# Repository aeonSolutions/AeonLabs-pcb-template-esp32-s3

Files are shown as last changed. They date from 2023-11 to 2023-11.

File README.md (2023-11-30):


  
 
 

<a href="https://trackgit.com">
trackgit-views
</a>




[](https://www.buymeacoffee.com/migueltomas)

[PCB-Prototyping-Catalogue](https://github.com/aeonSolutions/PCB-Prototyping-Catalogue)  >>  [DIY & Maker](https://github.com/aeonSolutions/PCB-Prototyping-Catalogue/blob/main/DIY-Maker/README.md)   >> 
 [DIY & Makers PCBs essentials: modules / Shields](https://github.com/aeonSolutions/PCB-Prototyping-Catalogue/blob/main/PCB-Shields/README.md)  >>  ESP32 S3 

<p align="right">
 <a href="https://github-com.translate.goog/aeonSolutions/PCB-Prototyping-Catalogue/tree/main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">Change Language</a> <br>
Last update: 30-11-2023
</p>

# PCB template ESP32 S3

<p align="center">
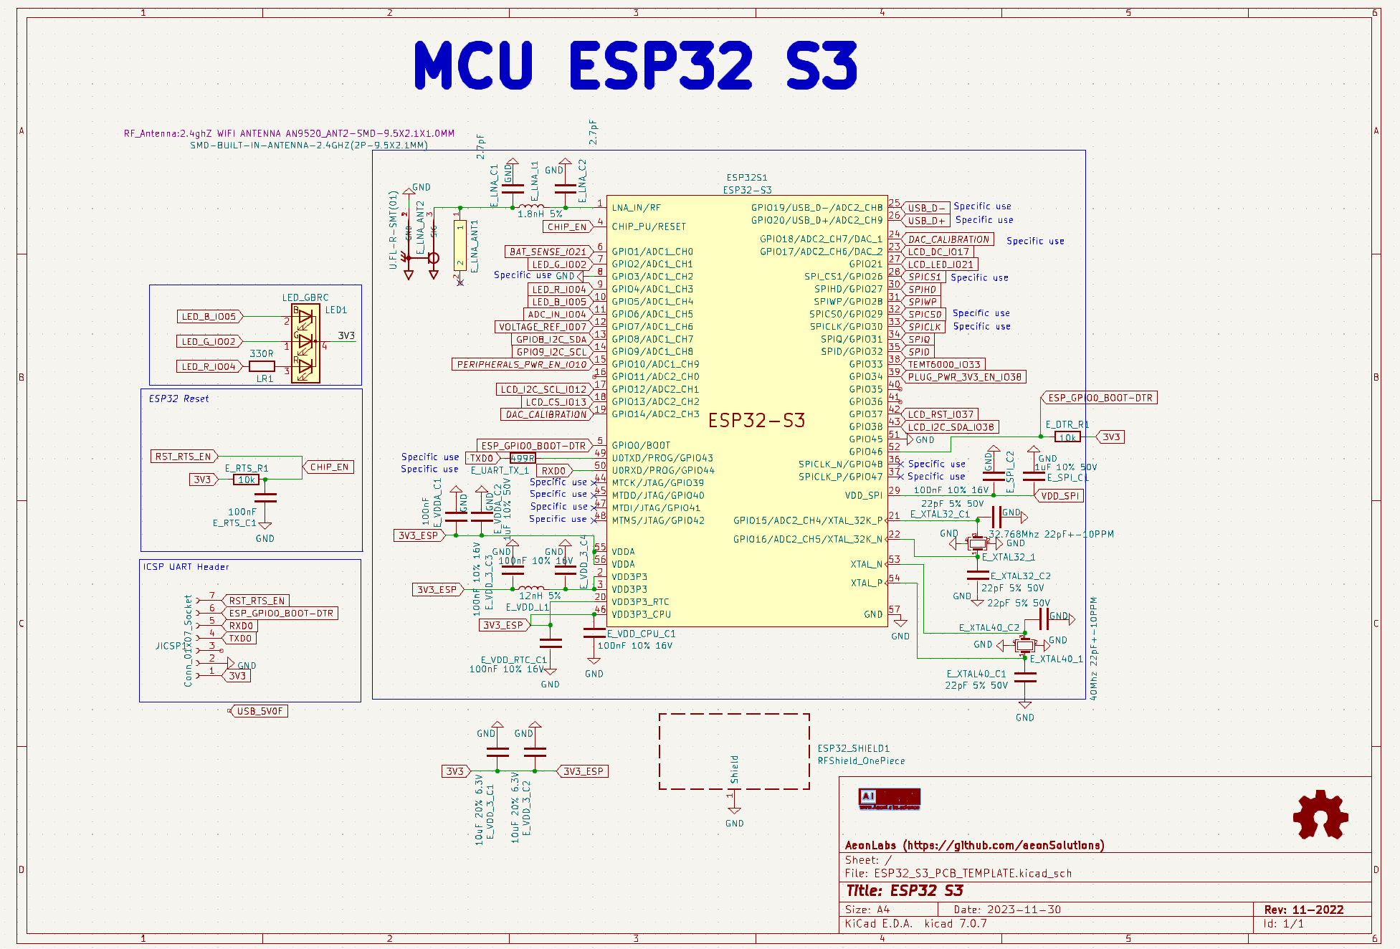
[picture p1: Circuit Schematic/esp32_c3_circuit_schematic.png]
   
</p>

#
## Firmware Download 
one can use the PCB in the repository [AeonLabs-MCU-Burner-USB-to-UART-TTL](https://github.com/aeonSolutions/AeonLabs-MCU-Burner-USB-to-UART-TTL) to program the ESP32 WROOM32 MCU on this PCB.

#

<br>

*Don't forget to LIKE , SHARE and subscribe the free whatsApp group* and if you liked this PCB consider buying me a cup of coffee. Links below.

## Liked it ? Get a Free PCB for yourself
Send me your Device or hardware and i will design a custom PCB for it. Free of charge. Contact-me on WhatsApp or email for more info. 

## Q&A WhatsApp Group
If you have any Questions or simply  like this kind of projects and want to stay updated with the latest research ideas and prototypes during the day and week, join the WhatsApp Group
[A.I. Things](https://chat.whatsapp.com/FkNC7u83kuy2QRA5sqjBVg)

## Fully assembled PCB
Alternatively, and if you do not want to build a PCB by yourself and like to buy one, you can do it here:

<p align="center">
   
</p>

<br />
<br />

## Author

You can get in touch with me on my LinkedIn Profile:

#### Miguel Tomas





You can also follow my GitHub Profile to stay updated about my latest projects: 

<br>

### Be supportive of my dedication and work towards technology education and buy me a cup of coffee
The PCB Desgin Files i provide here for anyone to use are free. If you like this Smart Device or use it, please consider buying me a cup of coffee, a slice of pizza or a book to help me study, eat and think new PCB design files.

<p align+"left">
<a href="https://www.buymeacoffee.com/migueltomas">
   
 </a>
<br>

</p>

<br />

### Make a donation on Paypal
Make a donation on paypal and get a TAX refund*.

(http://paypal.me/mtpsilva)

<br>

### Support all these open hardware projects and become a patreon  
Liked any of my PCB KiCad Designs? Help and Support my open work to all by becomming a LDAD Patreon.
In return I will give a free PCB design in KiCad to all patreon supporters. To learn more go to patreon.com. Link below.

(https://www.patreon.com/ldad)

#

### License

Before proceeding to download any of AeonLabs software solutions for open-source development and/or PCB hardware electronics development make sure you are choosing the right license for your project. See [AeonLabs Solutions for Open Hardware & Source Development](https://github.com/aeonSolutions/PCB-Prototyping-Catalogue/wiki/AeonLabs-Solutions-for-Open-Hardware-&-Source-Development) for more information.

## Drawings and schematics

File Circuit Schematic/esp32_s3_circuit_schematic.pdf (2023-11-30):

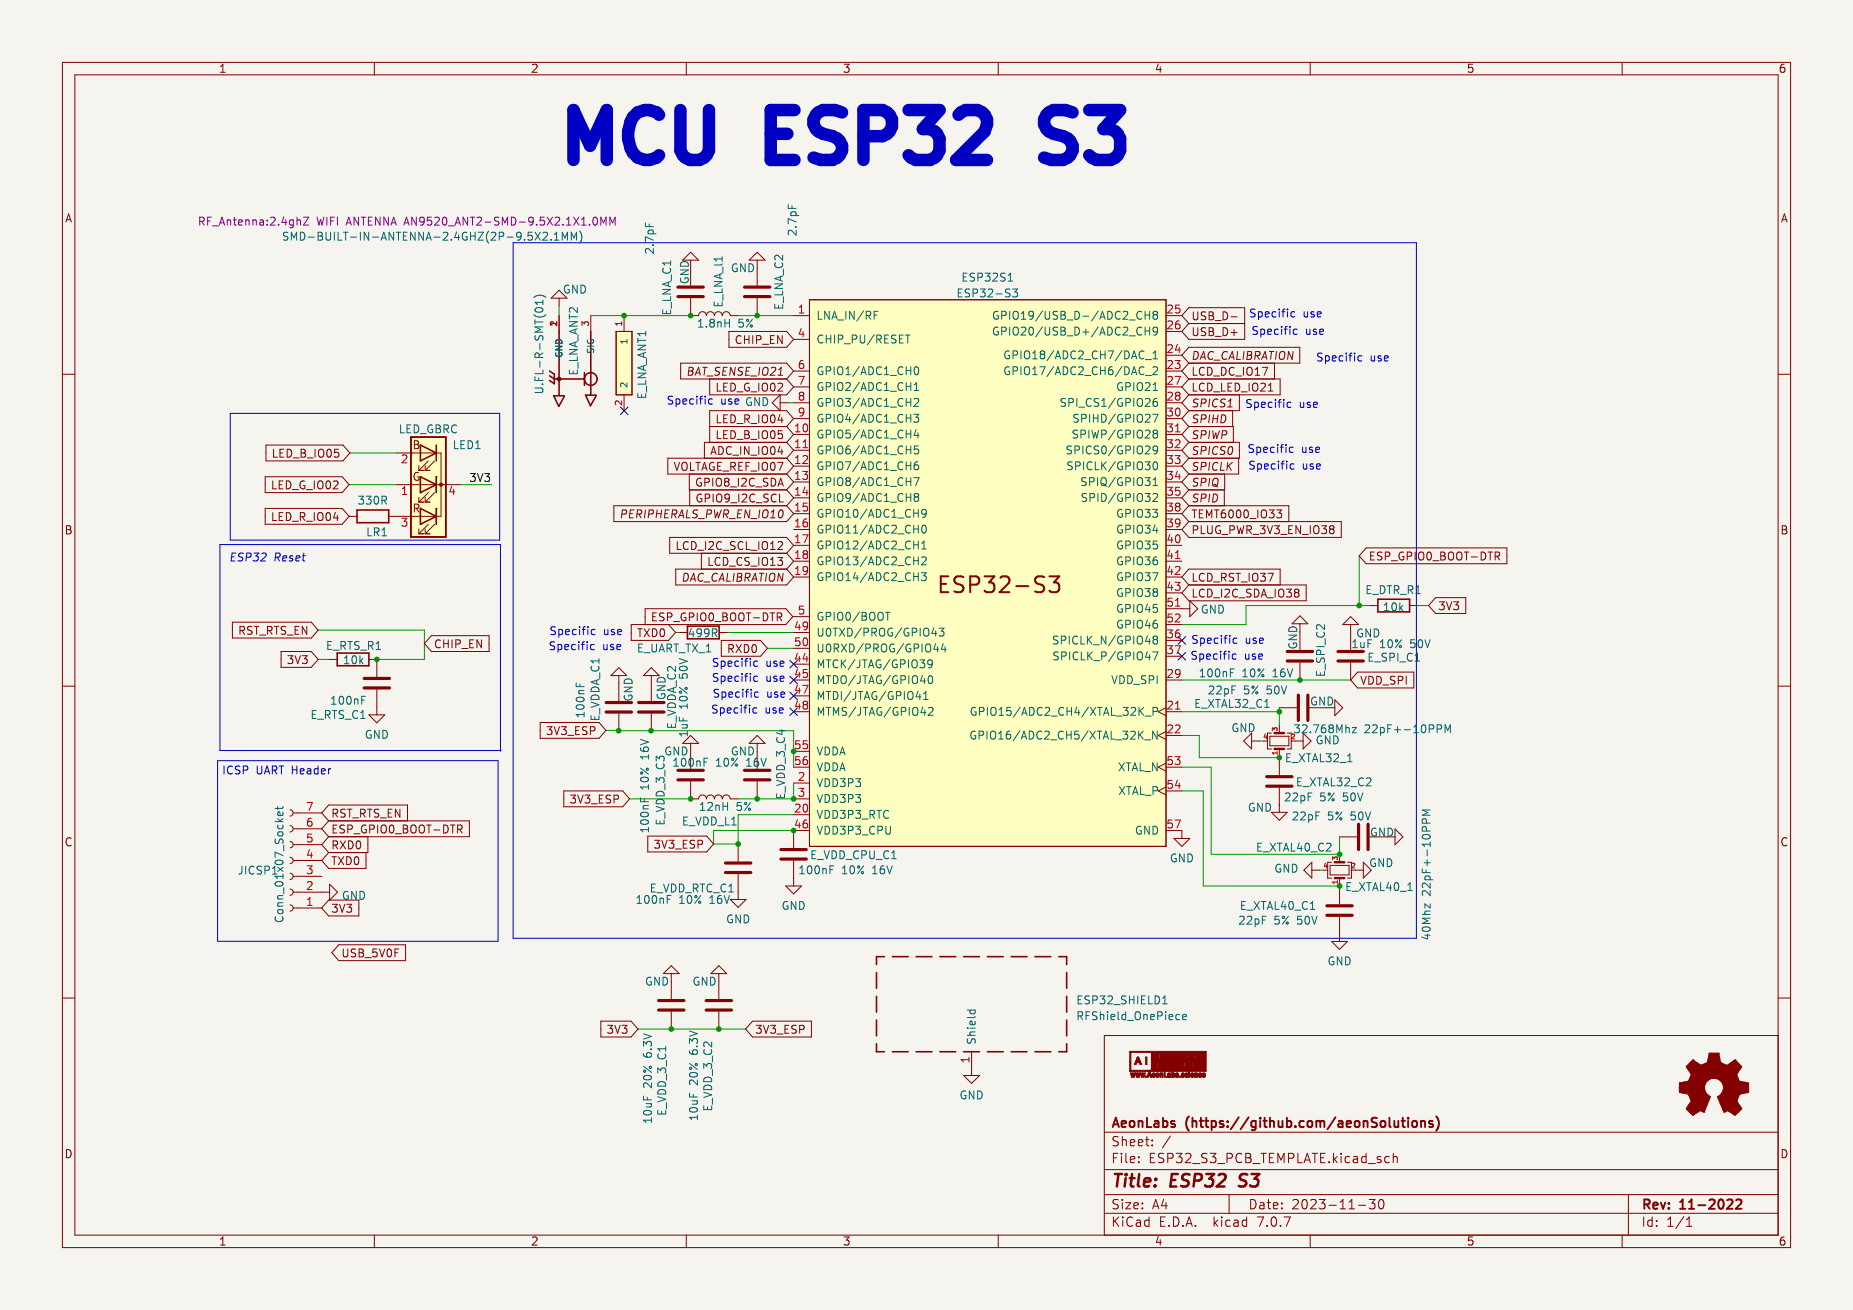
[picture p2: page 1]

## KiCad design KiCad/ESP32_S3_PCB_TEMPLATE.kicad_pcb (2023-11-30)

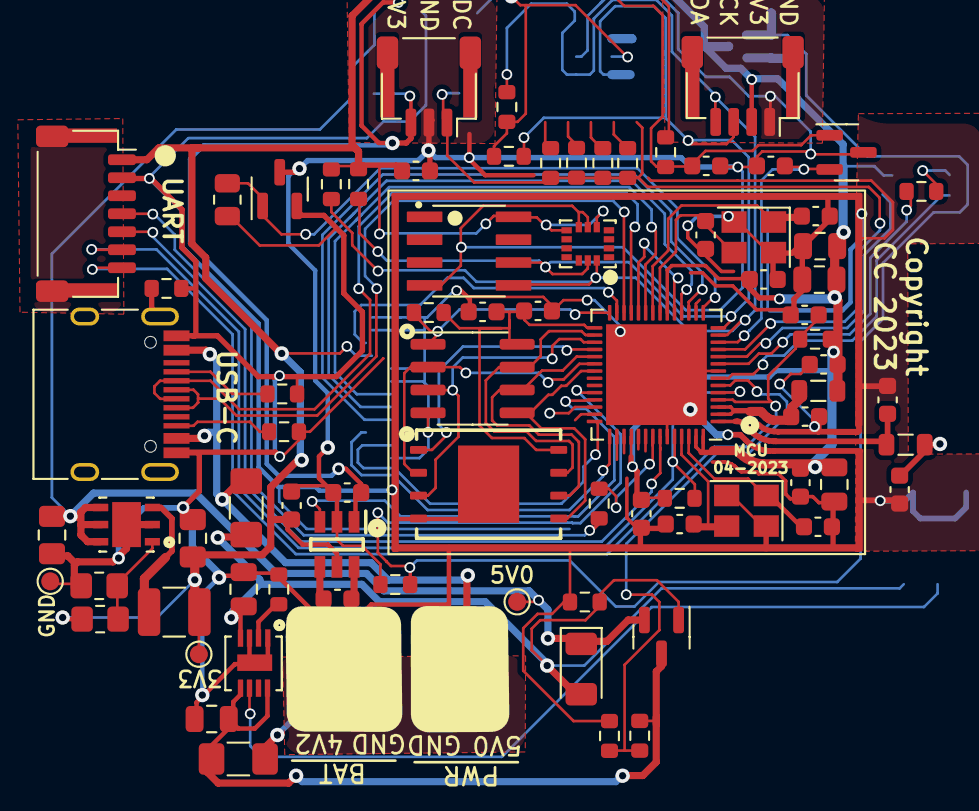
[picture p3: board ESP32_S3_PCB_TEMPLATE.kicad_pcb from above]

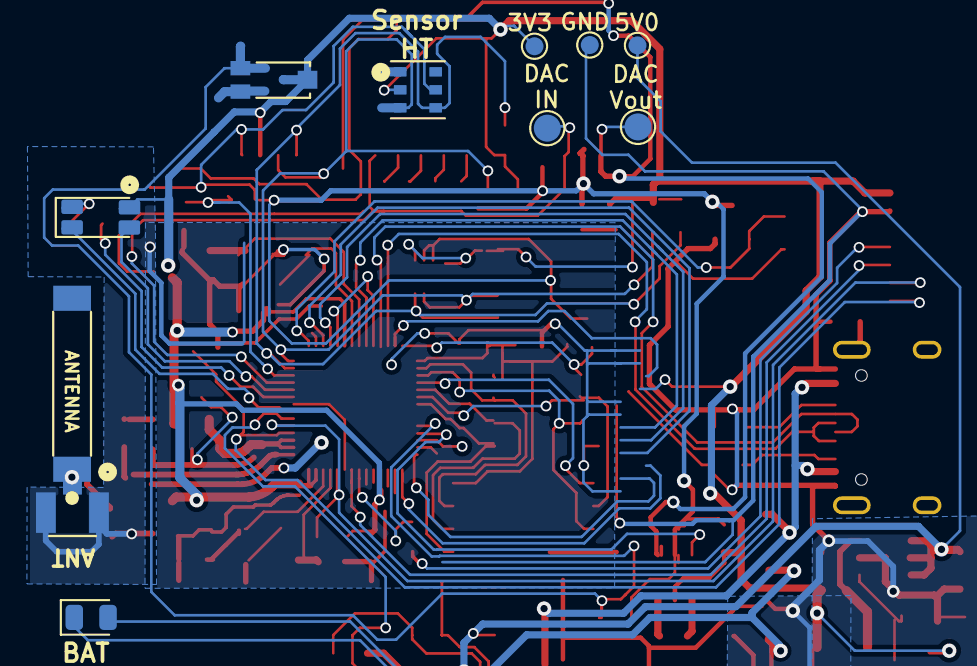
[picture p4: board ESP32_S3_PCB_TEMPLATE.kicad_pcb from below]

Board: 2 copper layers, 93 parts (12 on the bottom side), 53 nets.

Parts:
ATSHA_C1: 100nF; C_0603_1608Metric
AUR1: AUR9718x_DFN_3x3mm_6_pin; AUR9718 ST1S09 SON95P300X300X100-7N
AUR_C1: 22uF; C_0805_2012Metric_Pad1.18x1.45mm_HandSolder
AUR_C2: 4.7uF; C_0805_2012Metric_Pad1.18x1.45mm_HandSolder
AUR_R1: 75k; R_0805_2012Metric_Pad1.20x1.40mm_HandSolder
AUR_R2: 24k; R_0805_2012Metric_Pad1.20x1.40mm_HandSolder
AUR_l1: 3.3uF; L_1210_3225Metric
BAT_FUSE1: Polyfuse; Fuse_1206_3216Metric_Pad1.42x1.75mm_HandSolder
BAT_SENSE_R1, BAT_SENSE_R2: 100k; R_0603_1608Metric
CN3065_C2: 4.7uF; C_0805_2012Metric
CN3065_R1: 1K8; R_0603_1608Metric
CN3065_STDBY_LED1: LED; LED_0805_2012Metric
CN3965_C1: 22uF; C_0805_2012Metric
DIP_R1: 4k7; R_0603_1608Metric
DIP_R2: 1k; R_0603_1608Metric
DIP_R3: 20k; R_0603_1608Metric
DIP_R4: 200k; R_0603_1608Metric
DIP_R5: 2M; R_0603_1608Metric
DMP1045U_1: DMP1045U; SOT-23
DMP1045_R1: 10K; R_0603_1608Metric
DMP1045_SCHOT1: D_Schottky; D_1206_3216Metric
EPS1: ESP32-PSRAM_LY68L6400S; SOIC-8_3.9x4.9mm_P1.27mm
ESP32S1: ESP32-S3; QFN-56-1EP_7x7mm_P0.4mm_EP5.6x5.6mm
ESP32_SHIELD1: RFShield_OnePiece; ESP32-S3 GND Shield
ESP_FLASH1: W25Q128JVS; WSON8 FLASH SPI SON127P800X600X80-9N
E_DTR_R1: 10k; R_0603_1608Metric
E_LNA_ANT1: AN9520; 2.4ghZ WIFI ANTENNA AN9520_ANT2-SMD-9.5X2.1X1.0MM
E_LNA_ANT2: U.FL-R-SMT(01); RF Antenna IPEX SMD PCB HRS_U.FL-R-SMT(01)
E_LNA_C1, E_LNA_C2: 2.7pF; C_0603_1608Metric
E_LNA_l1: 1.8nH 5%; L_0805_2012Metric
E_RTS_C1: 100nF; C_0603_1608Metric
E_RTS_R1: 10k; R_0603_1608Metric
E_SPI_C1: 1uF 10% 50V; C_0603_1608Metric
E_SPI_C2: 100nF 10% 16V; C_0603_1608Metric
E_UART_TX_1: 499R; R_0603_1608Metric
E_VDDA_C1: 100nF; C_0603_1608Metric
E_VDDA_C2: 1uF 10% 50V; C_0805_2012Metric
E_VDD_3_C1, E_VDD_3_C2: 10uF 20% 6.3V; C_0805_2012Metric
E_VDD_3_C3, E_VDD_3_C4: 100nF 10% 16V; C_0603_1608Metric
E_VDD_CPU_C1: 100nF 10% 16V; C_0603_1608Metric
E_VDD_L1: 12nH 5%; L_0805_2012Metric
E_VDD_RTC_C1: 100nF 10% 16V; C_0603_1608Metric
E_XTAL32_1: 32.768Mhz 22pF+-10PPM; Crystal_SMD_3225-4Pin_3.2x2.5mm
E_XTAL32_C1, E_XTAL32_C2, E_XTAL40_C1, E_XTAL40_C2: 22pF 5% 50V; C_0603_1608Metric
E_XTAL40_1: 40Mhz 22pF+-10PPM; Crystal_SMD_3225-4Pin_3.2x2.5mm
ExtSW1: Conn_01x03_Female; JST_SH_SM03B-SRSS-TB_1x03-1MP_P1.00mm_Horizontal
ExtSWBAT_PLUG2: Conn_01x03_Female; JST_SH_SM03B-SRSS-TB_1x03-1MP_P1.00mm_Horizontal
HX1: HX4002; HX4002 SOT95 P280X125-6N
HX_C1, HX_C2, HX_C3: 2.2uF; C_0603_1608Metric
I2C_PLUG1: I2C6; JST_SH_SM04B-SRSS-TB_1x04-1MP_P1.00mm_Horizontal
I2C_SCL_R1, I2C_SDA_R1: 10k; R_0603_1608Metric
IMR1, IMR2: 10K; R_0603_1608Metric
IMU1: LSM6DS3; LSM6DS3 Motion Sensor PQFN50P300X250X86-14N
J1: TYPE-C-31-M-12; USB_C_Receptacle_HRO_TYPE-C-31-M-12
JICSP1: Conn_01x07_Socket; JST_SH_SM07B-SRSS-TB_1x07-1MP_P1.00mm_Horizontal
LED1: LED_GBRC; LED_1206_3210_RGB_Metric
LR1: 330R; R_0603_1608Metric
MTRR1: 10k; R_0805_2012Metric
MTRT1: NPN; SOT-23
PSRAM_R1: 100K; R_0603_1608Metric
PWR_FUSE1: Polyfuse; Fuse_1206_3216Metric_Pad1.42x1.75mm_HandSolder
PWR_PLUG1: Screw_Terminal_01x02; JST_SH_SM02B-SRSS-TB_1x02-1MP_P1.00mm_Horizontal
Sign-PbFree: LOGO_PBFREE
Sign-RecycleBin: LOGO_RECYCLEBIN_1
Sign-RoHS: LOGO_ROHS_1
TMPR1: 10K; R_0603_1608Metric
TP1, TP1#2: VIN; TestPoint_Pad_D1.0mm
TP2, TP2#2: VOut; TestPoint_Pad_D1.0mm
TP3, TP3#2: GND; TestPoint_Pad_D1.0mm
U1: MCP1525-TT; SOT-23
U2: ATSHA204A-MAHDA-T; ATSHA204A Auth SOIC8
U3: Battery_charger_CN3065_QFN8; QFN8 3.1x2.9mm QFNn-8 3x3 SON80P400X400X100-9N
U4: AHT20; AHT20 HT Sensor PSON100P300X300X110-6N
U6: TEMT6000; TEMT6000-SEN
USB_PLUG_R1, USB_PLUG_R3: 5k1; R_0603_1608Metric
USB_PLYG_R2: 150K; R_0603_1608Metric
VOLTAGE_REF_C1, VOLTAGE_REF_C2: 100nF; C_0603_1608Metric

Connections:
3V3: ATSHA_C1.2, AUR_C1.1, AUR_R1.1, AUR_l1.1, ESP32S1.20 (VDD3P3_RTC), ESP32S1.46 (VDD3P3_CPU), ESP32S1.55 (VDDA), ESP32S1.56 (VDDA), E_DTR_R1.1, E_RTS_R1.1, E_VDDA_C1.2, E_VDDA_C2.2, E_VDD_3_C1.1, E_VDD_3_C2.1, E_VDD_3_C3.1, E_VDD_CPU_C1.1, E_VDD_L1.1, E_VDD_RTC_C1.1, HX1.5 (VIN), HX_C3.2, I2C_PLUG1.2, I2C_SCL_R1.1, I2C_SDA_R1.2, IMR1.1, IMR2.1, IMU1.5 (VDDIO), IMU1.8 (VDD), JICSP1.1, LED1.4 (K), TP2.1, TP2#2.1, U2.8 (VCC), U4.2 (VDD), U6.COLLECTOR
3V3_PLUG: DIP_R1.2, ExtSW1.3, HX1.1 (VOUT), HX_C1.1, U1.1 (Vin), VOLTAGE_REF_C1.2
ADC_IN_IO04: DIP_R2.1, DIP_R3.1, DIP_R4.1, DIP_R5.1, ESP32S1.11 (GPIO6/ADC1_CH5), ExtSW1.1
BAT_SENSE_IO21: BAT_SENSE_R1.1, BAT_SENSE_R2.2, ESP32S1.6 (GPIO1/ADC1_CH0)
CHIP_EN: ESP32S1.4 (CHIP_PU/RESET), E_RTS_C1.2, E_RTS_R1.2, JICSP1.7
DAC_CALIBRATION: ESP32S1.19 (GPIO14/ADC2_CH3), ESP32S1.24 (GPIO18/ADC2_CH7/DAC_1)
ESP_GPIO0_BOOT-DTR: ESP32S1.5 (GPIO0/BOOT), ESP32S1.52 (GPIO46), E_DTR_R1.2, JICSP1.6
GND: AUR1.2 (GND), AUR1.7 (GND), AUR_C1.2, AUR_C2.2, AUR_R2.2, BAT_SENSE_R1.2, CN3065_C2.1, CN3065_R1.1, CN3965_C1.1, DMP1045_R1.2, EPS1.4 (VSS), ESP32S1.8 (GPIO3/ADC1_CH2), ESP32S1.51 (GPIO45), ESP32S1.57 (GND), ESP32_SHIELD1.1 (Shield), ESP_FLASH1.4 (GND), ESP_FLASH1.9 (GND), E_LNA_ANT2.1 (GND), E_LNA_ANT2.2 (GND), E_LNA_C1.2, E_LNA_C2.2, E_RTS_C1.1, E_SPI_C1.2, E_SPI_C2.2, E_VDDA_C1.1, E_VDDA_C2.1, E_VDD_3_C1.2, E_VDD_3_C2.2, E_VDD_3_C3.2, E_VDD_3_C4.2, E_VDD_CPU_C1.2, E_VDD_RTC_C1.2, E_XTAL32_1.2, E_XTAL32_1.4, E_XTAL32_C1.2, E_XTAL32_C2.2, E_XTAL40_1.2, E_XTAL40_1.4, E_XTAL40_C1.2, E_XTAL40_C2.2, ExtSWBAT_PLUG2.3, J1.B1, J1.B12, JICSP1.2, MTRR1.1, MTRT1.2, PWR_PLUG1.1, TP3.1, TP3#2.1, U3.1 (V_Temp), U3.3 (GND), U3.9 (GND), USB_PLUG_R1.2, USB_PLUG_R3.2, USB_PLYG_R2.2
GNDD: ATSHA_C1.1, ExtSW1.2, ExtSW1.MP, ExtSWBAT_PLUG2.MP, HX1.2 (GND), HX_C1.2, HX_C3.1, I2C_PLUG1.1, I2C_PLUG1.MP, IMU1.6 (GND), IMU1.7 (GND), JICSP1.MP, MTRT1.3, PWR_PLUG1.MP, TMPR1.1, U1.3 (Vss), U2.4 (GND), U4.5 (GND), VOLTAGE_REF_C1.1, VOLTAGE_REF_C2.1
GPIO8_I2C_SDA: ESP32S1.13 (GPIO8/ADC1_CH7), I2C_PLUG1.4, I2C_SDA_R1.1, IMR1.2, IMU1.14 (SDA), U2.5 (SDA), U4.4 (SDA)
GPIO9_I2C_SCL: ESP32S1.14 (GPIO9/ADC1_CH8), I2C_PLUG1.3, I2C_SCL_R1.2, IMR2.2, IMU1.13 (SCL), U2.6 (SCL), U4.3 (SCL)
LED_B_IO05: ESP32S1.10 (GPIO5/ADC1_CH4), LED1.2 (BA)
LED_G_IO02: ESP32S1.7 (GPIO2/ADC1_CH1), LED1.1 (GA)
LED_R_IO04: ESP32S1.9 (GPIO4/ADC1_CH3), LR1.1
unnamed: AUR1.1 (FB), AUR_R1.2, AUR_R2.1
unnamed: AUR1.3 (SW), AUR_l1.2
unnamed: ESP32S1.21 (GPIO15/ADC2_CH4/XTAL_32K_P), E_XTAL32_1.3, E_XTAL32_C1.1
unnamed: ESP32S1.22 (GPIO16/ADC2_CH5/XTAL_32K_N), E_XTAL32_1.1, E_XTAL32_C2.1
unnamed: ESP32S1.1 (LNA_IN/RF), E_LNA_C2.1, E_LNA_l1.2
unnamed: ESP32S1.49 (U0TXD/PROG/GPIO43), E_UART_TX_1.2
unnamed: ESP32S1.2 (VDD3P3), ESP32S1.3 (VDD3P3), E_VDD_3_C4.1, E_VDD_L1.2
unnamed: ESP32S1.53 (XTAL_N), E_XTAL40_1.3, E_XTAL40_C2.1
unnamed: ESP32S1.54 (XTAL_P), E_XTAL40_1.1, E_XTAL40_C1.1
unnamed: E_LNA_ANT1.1, E_LNA_ANT2.3 (SIG), E_LNA_C1.1, E_LNA_l1.1
unnamed: HX1.6 (C+), HX_C2.1
unnamed: HX1.4 (C-), HX_C2.2
unnamed: J1.A5 (CC1), USB_PLUG_R3.1
unnamed: J1.B5 (CC2), USB_PLUG_R1.1
unnamed: J1.S1 (SHIELD), USB_PLYG_R2.1
unnamed: LED1.3 (RA), LR1.2
unnamed: CN3065_R1.2, U3.2 (I_SET)
PERIPHERALS_PWR_EN_IO10: ESP32S1.15 (GPIO10/ADC1_CH9), MTRR1.2, MTRT1.1
PLUG_PWR_3V3_EN_IO38: ESP32S1.39 (GPIO34), HX1.3 (EN)
RXD0: ESP32S1.50 (U0RXD/PROG/GPIO44), JICSP1.5
SPICLK: EPS1.6 (SCLK), ESP32S1.33 (SPICLK/GPIO30), ESP_FLASH1.6 (CLK)
SPICS0: ESP32S1.32 (SPICS0/GPIO29), ESP_FLASH1.1 (~CS)
SPICS1: EPS1.1 (~CE), ESP32S1.28 (SPI_CS1/GPIO26), PSRAM_R1.1
SPID: EPS1.5 (SiO0), ESP32S1.35 (SPID/GPIO32), ESP_FLASH1.5 (DI(IO0))
SPIHD: EPS1.7 (SIO3), ESP32S1.30 (SPIHD/GPIO27), ESP_FLASH1.7 (IO3)
SPIQ: EPS1.2 (SIO1), ESP32S1.34 (SPIQ/GPIO31), ESP_FLASH1.2 (DO(IO1))
SPIWP: EPS1.3 (SIO2), ESP32S1.31 (SPIWP/GPIO28), ESP_FLASH1.3 (IO2)
STDBY_LED_G: CN3065_STDBY_LED1.1 (K), U3.6 (LED_DONE)
TEMT6000_IO33: ESP32S1.38 (GPIO33), TMPR1.2, U6.EMITTER
TXD0: E_UART_TX_1.1, JICSP1.4
USB_5V0: CN3065_STDBY_LED1.2 (A), CN3965_C1.2, DMP1045U_1.1, DMP1045_R1.1, DMP1045_SCHOT1.2 (A), PWR_FUSE1.1, U3.4 (VIN)
USB_5V0F: J1.A4, J1.A9, PWR_FUSE1.2, PWR_PLUG1.2
USB_D+: ESP32S1.26 (GPIO20/USB_D+/ADC2_CH9), J1.A6 (DP1), J1.B6 (DP2)
USB_D-: ESP32S1.25 (GPIO19/USB_D-/ADC2_CH8), J1.A7 (DN1), J1.B7 (DN2)
VDD_SPI: EPS1.8 (VCC), ESP32S1.29 (VDD_SPI), ESP_FLASH1.8 (VCC), E_SPI_C1.1, E_SPI_C2.1, PSRAM_R1.2
VIN: AUR1.4 (VIN_SW), AUR1.5 (VIN_A), AUR1.6 (EN), AUR_C2.1, DMP1045U_1.2, DMP1045_SCHOT1.1 (K), TP1.1, TP1#2.1
VIN_BAT: BAT_FUSE1.1, BAT_SENSE_R2.1, CN3065_C2.2, DMP1045U_1.3, U3.5 (BAT+), U3.8 (FB)
VIN_BATF: BAT_FUSE1.2, ExtSWBAT_PLUG2.1
VOLTAGE_REF_IO07: ESP32S1.12 (GPIO7/ADC1_CH6), U1.2 (Vout), VOLTAGE_REF_C2.2

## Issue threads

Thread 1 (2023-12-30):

PCb Board file malformed when opened with Kicad 7

freaf87, 2023-12-30:
Outline and some component seem missing from the board file
[Kicad Version]
Application: KiCad x86_64 on x86_64
Version: 7.0.9-7.0.9~ubuntu22.04.1, release build
Platform: Ubuntu 22.04.3 LTS, 64 bit, Little endian, wxGTK, ubuntu, wayland

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
Any idea what I m doing wrong ?
